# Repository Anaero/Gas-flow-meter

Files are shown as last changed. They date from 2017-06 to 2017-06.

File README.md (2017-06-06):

# Gas-flow-meter

The materials in this Repository have been designed to support data logging from the Anaero gas flow meter using a low cost Arduino based system (see http://www.anaero.co.uk/ for more information). All materials available from this repository are available subject to the terms and conditions of the Creative Commons CC BY-SA license (https://creativecommons.org/licenses/by-sa/4.0/).  Please see the licensing document in the repository for more information or visit the Creative Commons Web site.

No warranty, implied or otherwise, is granted in respect of the hardware designs or software available from this repository.

System overview - the hardware

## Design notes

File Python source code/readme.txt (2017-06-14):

Python source code developed using spyder 3.0.1 running with Python 3.5
Pyserial used to support serial comms with Arduino - available via Anaconda opensource platform (see https://www.continuum.io)

Startrun - used to transfer experimental data contained in setup.csv to Arduino at start of run.
Filegrab - transfers eventlog, hourly summary, daily summary and 4-hourly snapshot
Fastgrab - same as filegrab but only transfers eventlog and daily summary
Monitor - simple monitor program to 'eavesdrop' on what's happening

fastgrab/filegrab V2 - finds path for directory containing .exe file, checks for /data sub-directory and
creates sub-directory if not found. All data files are then written to /data sub-directory

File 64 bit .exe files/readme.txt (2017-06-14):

Windows 10 .exe files created from Python source code using Pyinstaller (see http://www.pyinstaller.org/).  

Note that Pyinstaller is not currently (as of June 2017) compatible with versions of Python above Python 3.5

fastgrab/filegrab V2 - finds path for folder containing executeable and creates /data sub-directory if it doesn't already exist
All log files are then written to the /data sub-directory

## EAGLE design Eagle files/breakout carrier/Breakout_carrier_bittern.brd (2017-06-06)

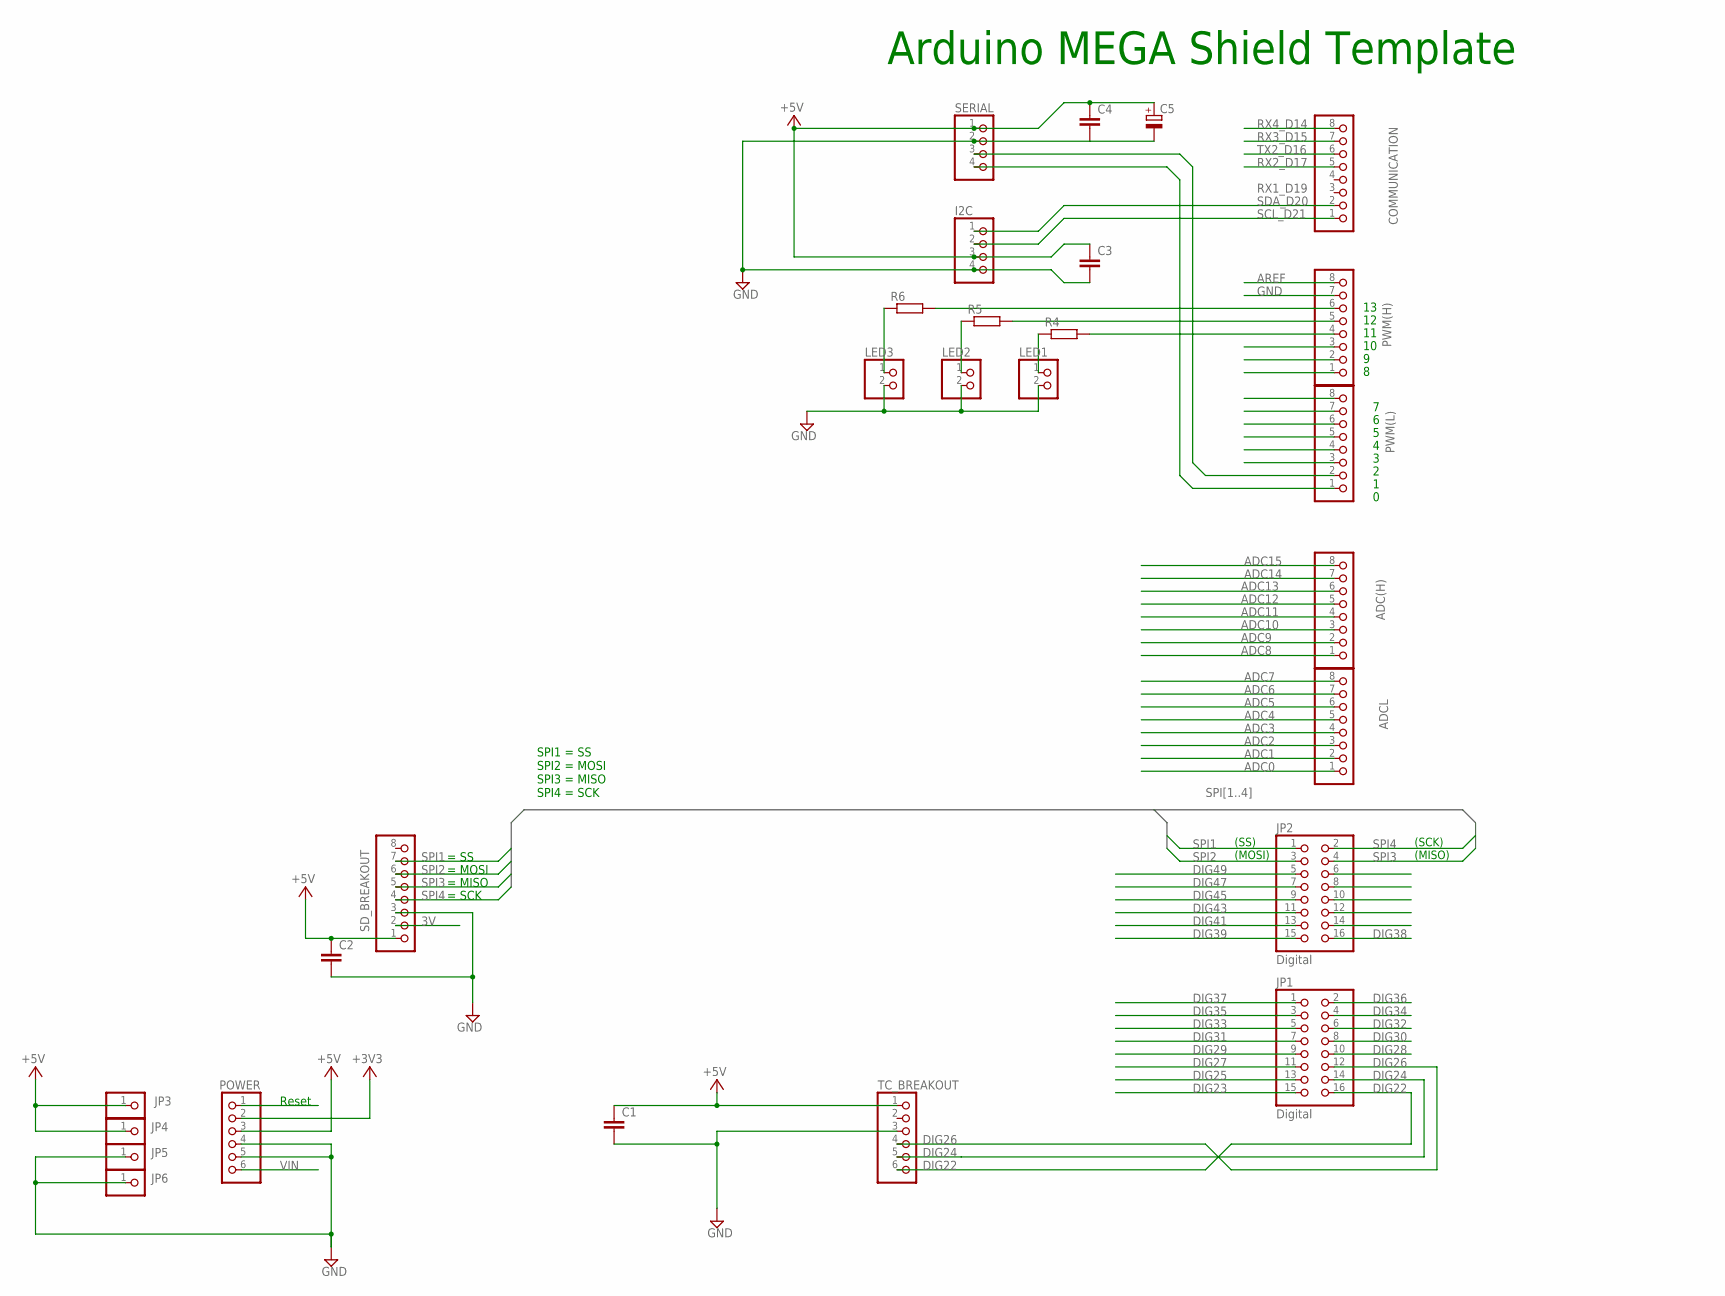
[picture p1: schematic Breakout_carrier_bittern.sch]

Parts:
ADC(H): PINHD-1X8; 1X08
ADCL: PINHD-1X8; 1X08
C1, C2, C3, C4: C-EU050-045X075; C050-045X075
C5: CPOL-EUE2.5-6; E2,5-6
COMMUNICATION: PINHD-1X8; 1X08
I2C: PINHD-1X4; 1X04
JP1, JP2: Digital; 2X08
JP3, JP4, JP5, JP6: PINHD-1X1; 1X01
LED1, LED2, LED3: PINHD-1X2; 1X02
POWER: PINHD-1X6; 1X06
PWM(H): PINHD-1X8; 1X08
PWM(L): PINHD-1X8; 1X08
R4, R5, R6: R-EU_0309/12; 0309/12
SD_BREAKOUT: PINHD-1X8; 1X08
SERIAL: PINHD-1X4; 1X04
TC_BREAKOUT: PINHD-1X6; 1X06

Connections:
3V: SD_BREAKOUT.2
+3V3: POWER.2
+5V: C1.1, C2.1, C3.1, C4.1, C5.+, I2C.3, JP3.1, JP4.1, POWER.3, SD_BREAKOUT.1, SERIAL.1, TC_BREAKOUT.1
ADC0: ADCL.1
ADC1: ADCL.2
ADC2: ADCL.3
ADC3: ADCL.4
ADC4: ADCL.5
ADC5: ADCL.6
ADC6: ADCL.7
ADC7: ADCL.8
ADC8: ADC(H).1
ADC9: ADC(H).2
ADC10: ADC(H).3
ADC11: ADC(H).4
ADC12: ADC(H).5
ADC13: ADC(H).6
ADC14: ADC(H).7
ADC15: ADC(H).8
AREF: PWM(H).8
DIG22: JP1.16, TC_BREAKOUT.6
DIG23: JP1.15
DIG24: JP1.14, TC_BREAKOUT.5
DIG25: JP1.13
DIG26: JP1.12, TC_BREAKOUT.4
DIG27: JP1.11
DIG28: JP1.10
DIG29: JP1.9
DIG30: JP1.8
DIG31: JP1.7
DIG32: JP1.6
DIG33: JP1.5
DIG34: JP1.4
DIG35: JP1.3
DIG36: JP1.2
DIG37: JP1.1
DIG38: JP2.16
DIG39: JP2.15
DIG41: JP2.13
DIG43: JP2.11
DIG45: JP2.9
DIG47: JP2.7
DIG49: JP2.5
GND: C1.2, C2.2, C3.2, C4.2, C5.-, I2C.4, JP5.1, JP6.1, LED1.2, LED2.2, LED3.2, POWER.4, POWER.5, PWM(H).7, SD_BREAKOUT.3, SERIAL.2, TC_BREAKOUT.3
unnamed: PWM(L).2, SERIAL.3
unnamed: PWM(H).4, R4.2
unnamed: PWM(H).5, R5.2
unnamed: PWM(H).6, R6.2
unnamed: LED3.1, R6.1
unnamed: LED2.1, R5.1
unnamed: LED1.1, R4.1
RESET: POWER.1
RX1_D19: PWM(L).1, SERIAL.4
RX2_D17: COMMUNICATION.5
RX3_D15: COMMUNICATION.7
RX4_D14: COMMUNICATION.8
SCL_D21: COMMUNICATION.1, I2C.2
SDA_D20: COMMUNICATION.2, I2C.1
SPI1: JP2.1, SD_BREAKOUT.7
SPI2: JP2.3, SD_BREAKOUT.6
SPI3: JP2.4, SD_BREAKOUT.5
SPI4: JP2.2, SD_BREAKOUT.4
TX2_D16: COMMUNICATION.6
VIN: POWER.6

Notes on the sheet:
Arduino MEGA Shield Template
(SS)
(MOSI)
(SCK)
(MISO)
Reset
= SCK
= MISO
= MOSI
= SS
SPI1 = SS SPI2 = MOSI SPI3 = MISO SPI4 = SCK

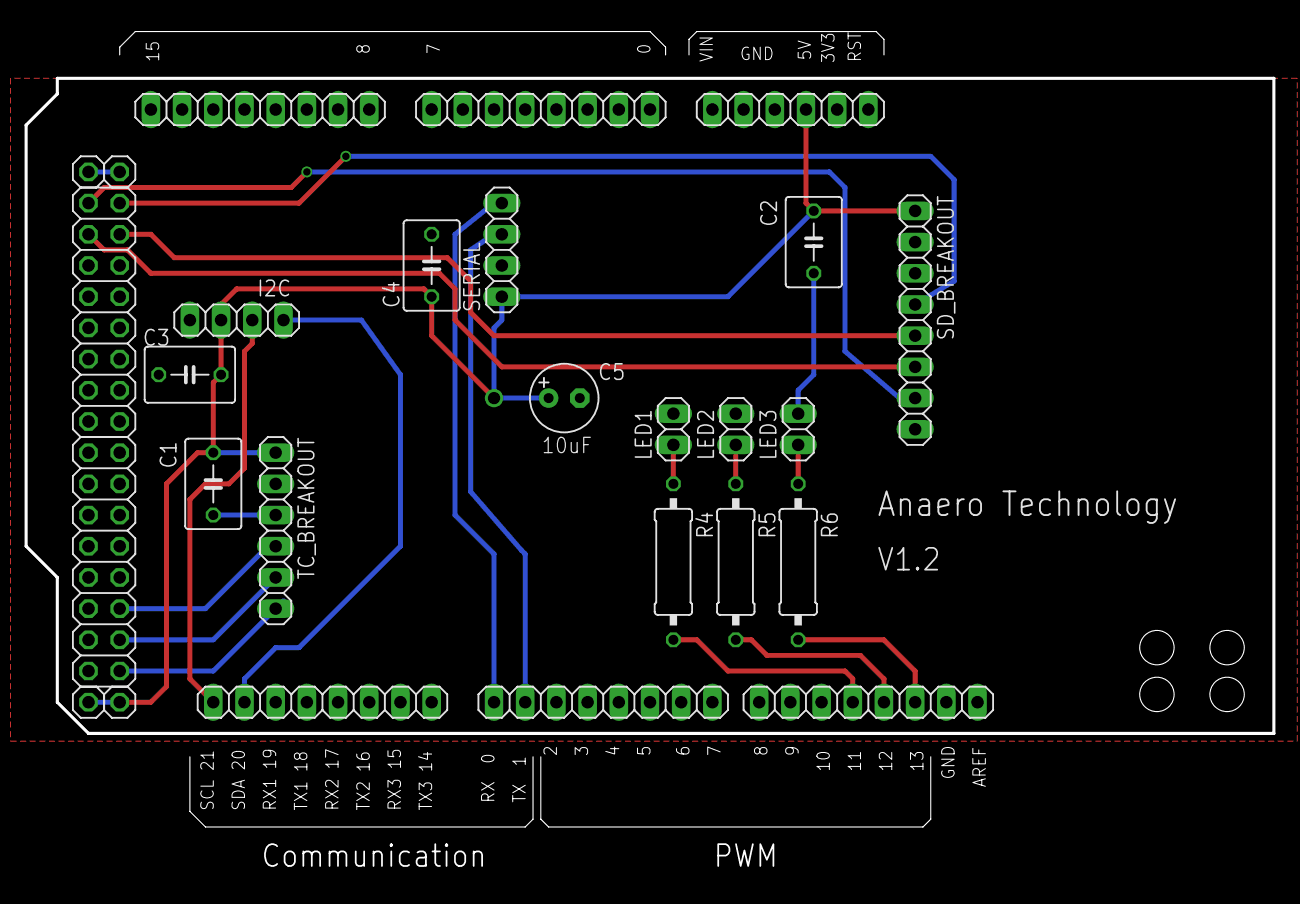
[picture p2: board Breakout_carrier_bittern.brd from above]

Board: 4 copper layers, 101.6 x 53.3 mm, 27 parts (0 on the bottom side), 19 nets.

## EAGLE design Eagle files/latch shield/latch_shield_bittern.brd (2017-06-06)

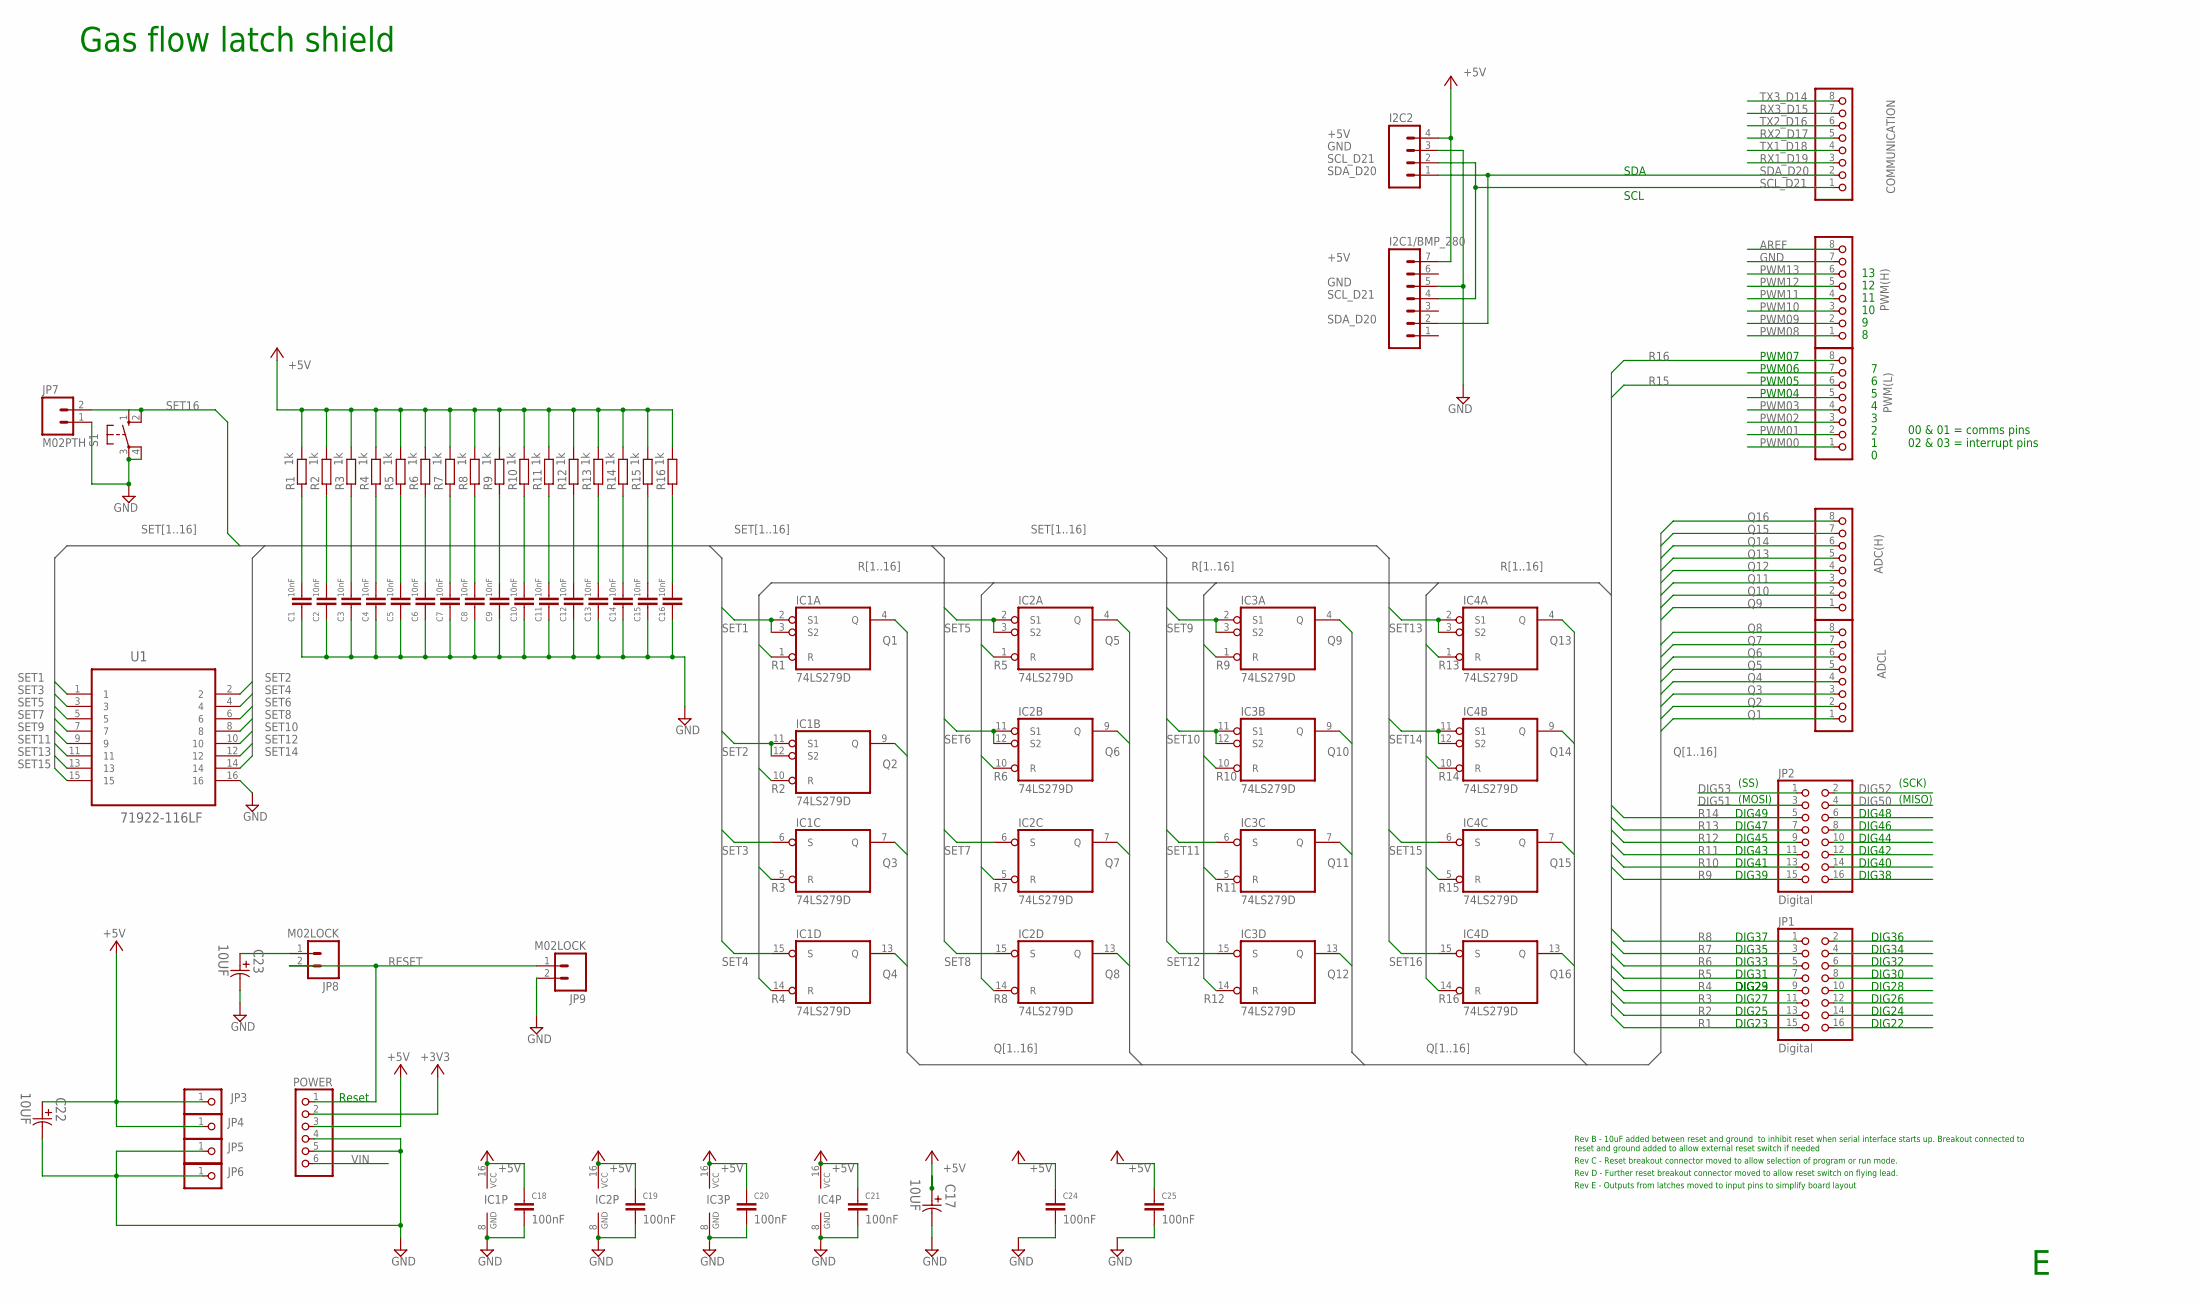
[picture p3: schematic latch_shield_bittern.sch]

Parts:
ADC(H): PINHD-1X8; 1X08
ADCL: PINHD-1X8; 1X08
C1, C2, C3, C4, C5, C6, C7, C8, C9, C10, C11, C12, C13, C14, C15, C16: 10nF; C0603
C17, C22, C23: 10UF; CAPAE530X610N
C18, C19, C20, C21, C24, C25: 100nF; C0603
COMMUNICATION: PINHD-1X8; 1X08
I2C1/BMP_280: M07; 1X07
I2C2: M04PTH; 1X04
IC1, IC2, IC3, IC4: 74LS279D; SO16
JP1, JP2: Digital; 2X08
JP3, JP4, JP5, JP6: PINHD-1X1; 1X01
JP7: M02PTH; 1X02
JP8, JP9: M02LOCK; 1X02_LOCK
POWER: PINHD-1X6; 1X06
PWM(H): PINHD-1X8; 1X08
PWM(L): PINHD-1X8; 1X08
R1, R2, R3, R4, R5, R6, R7, R8, R9, R10, R11, R12, R13, R14, R15, R16: 1k; R0603
S1: 10-XX; B3F-10XX
U1: 71922-116LF; FCI_71922-116LF

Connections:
+3V3: POWER.2
+5V: C17.1, C18.1, C19.1, C20.1, C21.1, C22.1, C24.1, C25.1, I2C1/BMP_280.7, I2C2.4, IC1.16 (VCC), IC2.16 (VCC), IC3.16 (VCC), IC4.16 (VCC), JP3.1, JP4.1, POWER.3, R1.2, R2.2, R3.2, R4.2, R5.2, R6.2, R7.2, R8.2, R9.2, R10.2, R11.2, R12.2, R13.2, R14.2, R15.2, R16.2
AREF: PWM(H).8
DIG50: JP2.4
DIG51: JP2.3
DIG52: JP2.2
DIG53: JP2.1
GND: C1.1, C2.1, C3.1, C4.1, C5.1, C6.1, C7.1, C8.1, C9.1, C10.1, C11.1, C12.1, C13.1, C14.1, C15.1, C16.1, C17.2, C18.2, C19.2, C20.2, C21.2, C22.2, C23.2, C24.2, C25.2, I2C1/BMP_280.5, I2C2.3, IC1.8 (GND), IC2.8 (GND), IC3.8 (GND), IC4.8 (GND), JP5.1, JP6.1, JP7.1, JP9.2, POWER.4, POWER.5, PWM(H).7, S1.3, S1.4 (P1), U1.16
unnamed: C23.1, JP8.1
PWM00: PWM(L).1
PWM01: PWM(L).2
PWM02: PWM(L).3
PWM03: PWM(L).4
PWM08: PWM(H).1
PWM09: PWM(H).2
PWM10: PWM(H).3
PWM11: PWM(H).4
PWM12: PWM(H).5
PWM13: PWM(H).6
Q1: ADCL.1, IC1.4 (Q)
Q2: ADCL.2, IC1.9 (Q)
Q3: ADCL.3, IC1.7 (Q)
Q4: ADCL.4, IC1.13 (Q)
Q5: ADCL.5, IC2.4 (Q)
Q6: ADCL.6, IC2.9 (Q)
Q7: ADCL.7, IC2.7 (Q)
Q8: ADCL.8, IC2.13 (Q)
Q9: ADC(H).1, IC3.4 (Q)
Q10: ADC(H).2, IC3.9 (Q)
Q11: ADC(H).3, IC3.7 (Q)
Q12: ADC(H).4, IC3.13 (Q)
Q13: ADC(H).5, IC4.4 (Q)
Q14: ADC(H).6, IC4.9 (Q)
Q15: ADC(H).7, IC4.7 (Q)
Q16: ADC(H).8, IC4.13 (Q)
R1: IC1.1 (R), JP1.15
R2: IC1.10 (R), JP1.13
R3: IC1.5 (R), JP1.11
R4: IC1.14 (R), JP1.9
R5: IC2.1 (R), JP1.7
R6: IC2.10 (R), JP1.5
R7: IC2.5 (R), JP1.3
R8: IC2.14 (R), JP1.1
R9: IC3.1 (R), JP2.15
R10: IC3.10 (R), JP2.13
R11: IC3.5 (R), JP2.11
R12: IC3.14 (R), JP2.9
R13: IC4.1 (R), JP2.7
R14: IC4.10 (R), JP2.5
R15: IC4.5 (R), PWM(L).6
R16: IC4.14 (R), PWM(L).8
RESET: JP8.2, JP9.1, POWER.1
RX1_D19: COMMUNICATION.3
RX2_D17: COMMUNICATION.5
RX3_D15: COMMUNICATION.7
SCL_D21: COMMUNICATION.1, I2C1/BMP_280.4, I2C2.2
SDA_D20: COMMUNICATION.2, I2C1/BMP_280.2, I2C2.1
SET1: C1.2, IC1.2 (S1), IC1.3 (S2), R1.1, U1.1
SET2: C2.2, IC1.11 (S1), IC1.12 (S2), R2.1, U1.2
SET3: C3.2, IC1.6 (S), R3.1, U1.3
SET4: C4.2, IC1.15 (S), R4.1, U1.4
SET5: C5.2, IC2.2 (S1), IC2.3 (S2), R5.1, U1.5
SET6: C6.2, IC2.11 (S1), IC2.12 (S2), R6.1, U1.6
SET7: C7.2, IC2.6 (S), R7.1, U1.7
SET8: C8.2, IC2.15 (S), R8.1, U1.8
SET9: C9.2, IC3.2 (S1), IC3.3 (S2), R9.1, U1.9
SET10: C10.2, IC3.11 (S1), IC3.12 (S2), R10.1, U1.10
SET11: C11.2, IC3.6 (S), R11.1, U1.11
SET12: C12.2, IC3.15 (S), R12.1, U1.12
SET13: C13.2, IC4.2 (S1), IC4.3 (S2), R13.1, U1.13
SET14: C14.2, IC4.11 (S1), IC4.12 (S2), R14.1, U1.14
SET15: C15.2, IC4.6 (S), R15.1, U1.15
SET16: C16.2, IC4.15 (S), JP7.2, R16.1, S1.1 (S), S1.2 (S1)
TX1_D18: COMMUNICATION.4
TX2_D16: COMMUNICATION.6
TX3_D14: COMMUNICATION.8
VIN: POWER.6

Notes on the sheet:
(SS)
(MOSI)
(SCK)
(MISO)
Reset
DIG22
DIG24
DIG26
DIG28
DIG30
DIG32
DIG34
DIG36
DIG38
DIG40
DIG42
DIG44
DIG46
DIG48
DIG23
DIG25
DIG27
DIG29
DIG31
DIG33
DIG35
DIG37
DIG39
DIG43
DIG41
DIG45
DIG47
DIG49
PWM07
PWM05
PWM04
PWM06
00 & 01 = comms pins 02 & 03 = interrupt pins
SDA
SCL

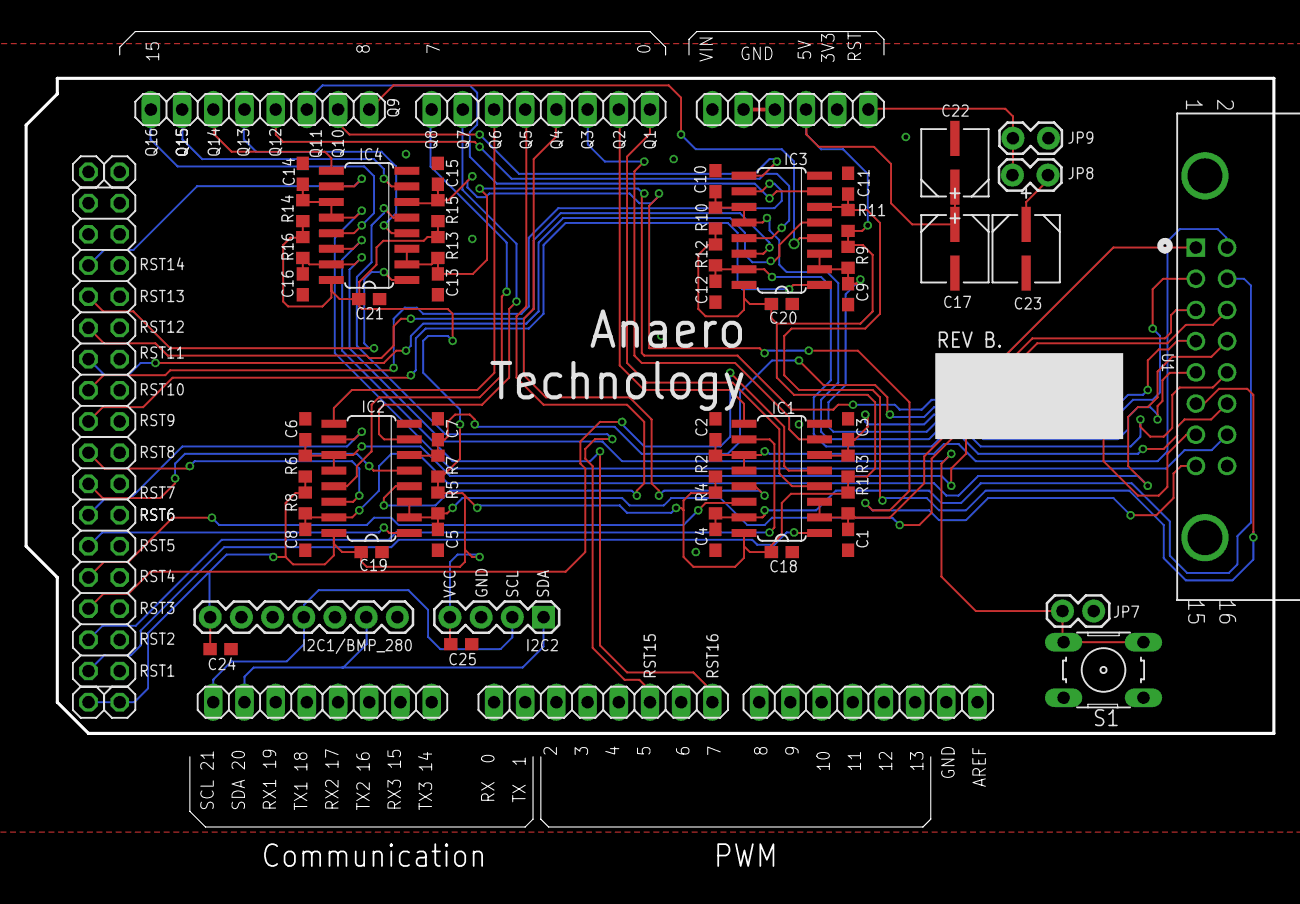
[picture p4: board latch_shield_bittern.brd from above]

Board: 4 copper layers, 101.6 x 53.3 mm, 64 parts (0 on the bottom side), 54 nets.

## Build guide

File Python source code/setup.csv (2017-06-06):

Sample description | In service | Inoculum only | Inoculum mass VS (g) | Sample mass VS (g) | Tumbler volume (ml)
Inoculum 1 | 1 | 1 | 15.46 | 0 | 5
Inoculum 2 | 1 | 1 | 15.48 | 0 | 5.2
Inoculum 3 | 1 | 1 | 15.5 | 0 | 5.17
Cellu 10 | 1 | 0 | 14.27 | 2.39 | 5.17
Cellu 11 | 1 | 0 | 14.28 | 2.42 | 5
Cellu 12 | 1 | 0 | 14.27 | 2.38 | 5
1623 Mar | 1 | 0 | 15.31 | 3.92 | 5.17
1623 Mar | 1 | 0 | 15.32 | 3.87 | 5
1623 Mar | 1 | 0 | 15.3 | 3.83 | 5
1624 Agri | 1 | 0 | 11.85 | 2.97 | 5
1624 Agri | 1 | 0 | 11.8 | 2.98 | 5.17
1624 Agri | 1 | 0 | 11.8 | 2.98 | 5.17
54 Bryn 1 | 1 | 0 | 11.92 | 3.1 | 5.17
54 Bryn 2 | 1 | 0 | 11.9 | 2.95 | 5.17
54 Bryn 3 | 1 | 0 | 11.88 | 2.96 | 5.17
End of data
Notes:
...To designate a reactor as inoculum only enter a 1 in column C otherwise enter 0
...Only tumblers which are marked as in service (a 1 in column B) will be monitored
...If a channel is not being used enter a 0 in column B
...The sample descriptions given in column A can be made up of any character or number combination but MUST NOT contain a comma!
...All cells in rows 2 to 16 MUST be populated - do not leave any blank or empty!
...Cell A17 should contain the words 'End of data'

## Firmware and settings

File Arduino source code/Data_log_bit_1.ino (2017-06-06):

 //
// Gas flow data logging program
//
// Bittern build 
//
// This version is for use with the Mark 2 latch shield, the Adafruit MAX31855K thermocouple amp and type K thermocouple, the BMP280 pressure sensor, the 
// Adafruit micro-SD breakout board and the Adafruit 16x2 RGB LCD display.
// I2C devices: BMP280 pressure sensor addr - 0x77; RGB LCD display - addr 0x20
// micro SD breakout uses hardware SDI (i/o pins 50, 51, 52, 53) with digital output 53 as Card Select
// MAX31855K thermocouple amp uses software SDI running on digital i/o pins 22-CLK, 24-CS and 26-DO (no DI pin needed)
// 
//
// 
//
// Time delay before attempting to clear any latches which have been set ~ 9 seconds
// ml/g output reported for inoc only channels as well as sample channels
// hour log and day log report both incremental and cumulative ml/g
// column headings only written to SD log files at very start of run
// inService channels now identified as inService(= 1), taken out of service by user in setup.csv (= 0), identified as stuck by Arduino (= -1)
// running monitor utility triggers reset attempt for any channels marked with inService = -1 (i.e. any which have been automatically removed from service by arduino)
// LED's on pins 13 (red), 12 (yellow), 11 (green)
// If temperature reported is below zero or below (disconected temp sensor) - last positive temp is used in calculations and alarm is set until problem clears
// Serial port data rate set to 57600 bps
// Serial timeout set to 500 ms
//
// Avocet build (retired 4/5/2017)
// time delay eolDelay introduced at the end of each line transmitted for compatibility with Bluetooth/slower machines
// dummy string added at laptop end to each line of setup data to ensure correct parsing when sample name starts with one or more digits
//
// Bittern build released 4/5/2017
// Build name displayed on LCD panel and sent to console at start up to aid identification/config management
// inoculumOnly variable changed from boolean to int to allow range check as startup data is transferred - helps to detect framing errors/range errors in setup data and/or parsing
// range checking on data transferred from laptop implemented, warnings issued if InService is other than 0 or 1, inoculum only is other than 0 or 1, tumbler volume less than
// 4ml or greater than 14 ml, inoculum only channels have a non zero entry in the sample VS column - provides added protection against user error and framing error in data transfer
// '^' used as end of line delimiter to allow extraneous characters in setup file to be skipped to avoid framing errors
// auto-reset performed at every pingcount cycle on any channels marked as stuck by arduino (i.e. where inService[i] = -1) - only truly stuck channels will remain stuck
// support for fastGrab utility added - reads back eventlog and daily log only (filgrab still works and does full file transfer)
// hangover time can be adjusted from setup.csv file by replacing 'End of data' with an integer between 8 and 35 seconds - default setting is ~ 15 seconds
// 
//

#include <Wire.h>
#include <SPI.h>
#include <SD.h>
//#include "Adafruit_MCP9808.h"
#include <Adafruit_MAX31855.h>
#include <Adafruit_Sensor.h>
#include <Adafruit_BMP280.h>
#include <Adafruit_RGBLCDShield.h>
#include <utility/Adafruit_MCP23017.h>
#define MAXDO   26
#define MAXCS   24
#define MAXCLK  22
//
// set up variable types using the SD utility libraries
//
Sd2Card card;
SdVolume volume;
SdFile root;
//
// set up sensor objects
// 
Adafruit_MAX31855 thermocouple(MAXCLK, MAXCS, MAXDO); // set up thermocouple object
Adafruit_BMP280 bme;                                  // set up BMP280 pressuere sensor object (using I2C bus option)
Adafruit_RGBLCDShield lcd = Adafruit_RGBLCDShield();  // set up LCD shield object
//
// set up i/o channels and arrays
//
const int chipSelect = 53;
byte Q[17];                   // mapping between between latch outputs (active high)and Arduino inputs
byte R[17];                   // mapping between Arduino outputs and latch resets (active low)
float sampleVS[16];           // mass of volatile solids in each sample under test (user provided)
float inocVS[16];             // mass of volatile solids from inoculum in each sample (user provided)
String alphaName1, alphaName2, alphaName3, alphaName4, alphaName5, alphaName6, alphaName7, alphaName8;           //set up string objects
String alphaName9, alphaName10, alphaName11, alphaName12, alphaName13, alphaName14, alphaName15, alphaName;      //for alphanumeric ch names
String discard;                // used to force parsing of setup data at end of line
long ChannelCount[17];        // used to store cumulative total of number of tumbles recorded per channel
float tumblerVol[16];         // calibrated volume of each tumbler
float totalVol[16];           // used to store cumulative total volume of gas collected on each channel at STP
float volThisTip[16];         // volume of gas at STP from the most recent tip 
float volThisDay[16];         // running total of volume of gas at STP during current day 
float volThisHour[16];        // running total of volume of gas at STP during current hour
int inService[17];            // marks channels as in service or out of service (0 = not in service, 1 = in service, -1 = removed from service following reset fail)
boolean resetFlag[17];        // used to indicate which channels (if any) need to be queued for reset after each latch scan
boolean delayFlag = false;    // binary flag to indicate at least one channel in need of reset
int inoculumOnly[16];         // marks those channels which contain only innoculum - use int rathern than bool to help detect errors in setup data transfer/parsing 
boolean gotTemp = false;      // flag to bypass temp get if just got
boolean gotPress = false;     // flag to bypass press get if just got
float netVol_per_gram[16];    // total volume less average of inoc only volume divided my mass of vol solids (so ml/g)
float netVol_per_gramDay[16]; // netVol_per_gram calculatede for this day
float netVol_per_gramHour[16];// netVol_per_gram calculated for this hour
int tipsThisDay[16];          // running total of tumbler tips during current day
int tipsThisHour[16];         // running total of tumbler tips during current hour
unsigned long time_offset;    // records time at which run commences
unsigned long timex;          // time in ms since start of run
double dtemp;
float temperature;            // temp reading
float baroPress;              // barometer presssure reading
float pressLast;              // stores last recorded valid pressure in case of sensor failure
float tempLast ;              // stores last recorded valid temp in case of sensor failure
float contAve;                // inoculum only output in ml per gram for each inoc only cell averaged over all inoc only channels
int n;                        // counter used to calculate final contAve average
int goFlag = 0;               // used for handshake between Arduino and Phython front end
int startMode = 1000;         // 1000 = normal cold start; 500 = recovery after unwanted reset (not programmed yet)
int alphaIndex;               // used to pass index to get_alphaName function
byte R_LED = 13; byte Y_LED = 12; byte G_LED = 11;  //assignement of Arduino pins to diagnostic LEDs
int ByteReceived = 0;
const int chipSelect1 = 53;
const char comma=(',');
int cardFound;
int cardPresent;
int snapTest;
long days=0;
int newDay=0;
int oldDay=0;
long hours=0;
int newHour=0;
int oldHour=0;
long mins=0;
int newMins=0;
int oldMins=0;
long secs=0;
int oldSecs=0;
int newSecs=0;
int secTest=0;
int incomingByte=0;
int  pingCount = 0;
int dispCount;
int hangTime = 15;                               // length of pause before attempting to clear latches that have been set
int hangTimeReset; 
int fastGrab = 0;                                // used to select full file transfer (filegrab utiltity) or eventlog and daily only (fastgrab utility)
File fSetup;
File fEventLog;
File fDaily;
File fHourly;
File fSnap;
byte sdByte;
int eolDelay=65;                                 // end of line delay to allow bluetooth/laptop to process
String fnameToCheck;
String fnameSetup = "setup.csv";
String fnameEvent = "eventlog.csv";
String fnameDaily = "daily.csv";
String fnameHourly = "hourly.csv";
String fnameSnap = "snapshot.csv";
String fnameError = "errorlog.csv";
//
//
//
void setup() {
//
// setup i/0 channel assignments
//  
   Q[1]=54, Q[2]=55, Q[3]=56, Q[4]=57, Q[5]=58, Q[6]=59, Q[7]=60, Q[8]=61;          // feed to arduino from latches 
   Q[9]=62, Q[10]=63, Q[11]=64, Q[12]=65, Q[13]=66, Q[14]=67, Q[15]=68, Q[16]=69;   // corresponds to A0 through A15
//
//
//
   R[1]=23, R[2]=25, R[3]=27, R[4]=29, R[5]=31, R[6]=33, R[7]=35, R[8]=37;          // latch reset lines
   R[9]=39, R[10]=41, R[11]=43, R[12]=45, R[13]=47, R[14]=49, R[15]=5, R[16]=7; 

//
// Set up pins as inputs and outputs
//
for (int i=1; i<=15; i++){
   pinMode(R[i], OUTPUT);
   pinMode(Q[i], INPUT);
   digitalWrite(R[i], HIGH);   digitalWrite(R[i], LOW);   digitalWrite(R[i], HIGH);
   }
//
//
//
   Serial.begin(57600);
   Serial.setTimeout(500);             // set serial timeout to 0.5 second - increase this if using manual input instead of Python utilities
   lcd.begin(16, 2); 
//
   pinMode(R_LED, OUTPUT);                                                         // set up pins to LEDs as outputs - nut used at the moment
   pinMode(Y_LED, OUTPUT);  
   pinMode(G_LED, OUTPUT); 

   digitalWrite(R_LED, HIGH);                                                       // turn on all LEDs
   digitalWrite(Y_LED, HIGH);
   digitalWrite(G_LED, HIGH);
// 
// program held here until something received on serial port
//
//
// Send reset message every 100ms until incoming data received
//   
   while(goFlag == 0) {
       Serial.println(F("Arduino has been reset"));
       delay(100);
       goFlag = Serial.available();
       }
   lcd.print("hello :-)       ");
   lcd.setCursor(0,1);
   lcd.print("getting ready...");
   delay(2000);
//
//
//
   lcd.setCursor(0,0);                                                          // dispaly bild name
   lcd.print("running         ");
   lcd.setCursor(0,1);
   lcd.print("Bittern build   ");
   delay(5000);
//      
   startMode = Serial.parseInt();                                               // read start mode number supplied by python utility
//       
   Serial.println();
   Serial.println(F("Arduino running - starting self test"));
   Serial.println();
   Serial.println(F("Running Bittern software build"));                         // display software build name
   Serial.println();
// 
   lcd.setCursor(0,0);                                                          // set up the LCD's number of columns and rows: 
   lcd.print("starting self   ");
   lcd.setCursor(0,1);
   lcd.print("test            ");
//
/*    code for MCP9808 I2C temp sensor
      if (!tempsensor.begin()) {                                                   // open temp sensor and check is OK
      Serial.println(F("Temperature sensor not responding"));
      while (1);                                                                // program will loop here continuously if no response from temp sensor
      }
   else {
       Serial.println(F("Temperature sensor OK"));       
       tempsensor.shutdown_wake(0);                                             // wake up temp sensor - required before reading temp
       delay(10);
       temperature = tempsensor.readTempC();
       delay(250);                                                              // give sensor time to respond!
       Serial.print(F("Temp: ")); Serial.print(temperature); Serial.println("C");                                        
       tempsensor.shutdown_wake(1);                                            // shutdown temp sensor to reduce power consumption       
       }
//
   delay(250);  // give time for temp sensor shutdown messaging to complete
*/
//
// Check thermocouple
//
   Serial.print("Internal Temp = ");
   Serial.println(thermocouple.readInternal());
   dtemp = thermocouple.readCelsius();
   if (isnan(dtemp)) {
     Serial.println(F("Thermocouple not registering - please check"));
   } else {
     temperature = (float) dtemp;
     Serial.print("Thermocouple reading is "); 
     Serial.print(temperature);
     Serial.println( "C");
   }
//
//
//
   if (!bme.begin()) {                                                              // open pressure sensor and check is OK
       Serial.println(F("Barometer not responding"));
       digitalWrite(R_LED, HIGH); digitalWrite(Y_LED, LOW);   digitalWrite(G_LED, LOW);   // set red LED to indicate problem
       lcd.setCursor(0,0);                                                                // set up the LCD's number of columns and rows: 
       lcd.print("problem with    ");
       lcd.setCursor(0,1);
       lcd.print("barometer       ");
       while (1);                                                                   // program will loop here in event of barometer failure
       }
   else{     
      Serial.println(F("Barometer OK"));
      bme.begin();                                                                  // re initialise pressure sensor
      delay(15);
      baroPress = bme.readPressure();                                               // take first reading to force BMP internals and discard  
      delay(15);
      baroPress = bme.readPressure();                                               // valid pressure reading
      delay(15);      
      baroPress = baroPress / 100; 
      Serial.print(F("Air pressure is: ")); Serial.print(baroPress); Serial.println(" hPa");
      }
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
void loop() { 
   timex = (millis() - time_offset);                            // capture current time before scanning latches
   uptime();                                                    // takes 'timex' variable and convert elapsed run time to days and hours mins and secs  
   screenTime();                                                // call function to print time since reset to LCD screen
//
// send updated time over serial link every 10 seconds (could do with converting to a function to improve readability)
//
   secTest = (newSecs / 10) * 10;
   if ((newSecs != oldSecs) && (secTest == newSecs)) {
      if (days <=9) {
         Serial.print("0");
         }
      Serial.print(days);
      Serial.print(":");
      if (hours <=9) {
         Serial.print("0");
         }
      Serial.print(hours);
      Serial.print(":");
      if (mins <=9) {
        Serial.print("0");
        }
      Serial.print(mins);
      Serial.print(":");
      if (secs <=9) {
         Serial.print("0");
         }      
      Serial.println(secs);         
      }  
//
// Serial comms bit done
//     
   if (oldDay != newDay) {                                                                  // check whether daylog or hourlog need to be writted to SD card
      write_day_log();  
//
// zero out day counters
//
      for (byte i=1; i<=15; i++) {
         tipsThisDay[i] = 0;
         volThisDay[i] = 0;  
         }
      }
   if (oldHour != newHour) {      
      write_hour_log();  
//
// zero out hour counters
//            
      for (byte i=1; i<=15; i++) {
         tipsThisHour[i] = 0;
         volThisHour[i] = 0.0;  
         }
      snapTest = (newHour/4) * 4;
      if (snapTest == newHour) {
         write_snapshot();
        }   
      }
//
// Now scan all in service latches and update data log accordingly
//   
   for(byte i=1; i <= 15; i++) {                                                            // check each channel in turn to see if any have tripped
      if((inService[i]== 1) && (digitalRead(Q[i])== HIGH)) {                                // identifies in service channels which have been triggered
         lcd.setCursor(0, 1);
         lcd.print("event on ch "); lcd.print(i);
         digitalWrite(Y_LED, HIGH);
         ChannelCount[i] = ChannelCount[i] + 1;                                             // increment relevant channel activity counter
         tipsThisDay[i] = tipsThisDay[i] + 1;
         tipsThisHour[i] = tipsThisHour[i] + 1;
         resetFlag[i] = true;                                                               // mark channel for reset - this can only happen if channel is in service at this point
         delayFlag = true;                                                                  // set delay flag to force delay before reset as at least one ch has triggered - no problem if set several times
//
// Get barometer reading if not already updated
//
         if(gotPress == false) {
            baroPress = bme.readPressure();
            delay(10);
            baroPress = baroPress / 100.0;                                                  // convert frpm pA to HpA
            digitalWrite(R_LED, LOW);                                                       // clear red LED
            lcd.setCursor(0, 0);                                                            //
            lcd.print("data log running");                                                  // reset screen message
            if (baroPress >= 1200.0){                                                       // excessive pressure used to indicate sensor fail/not connected
               digitalWrite(R_LED, HIGH);                                                   // set red LED to indicate problem
               lcd.setCursor(0, 0);
               lcd.print("bmp sensor alert");
               baroPress = pressLast;                                                       // substitute previous pressure reading
               }
            gotPress = true;
            pressLast = baroPress;
            }  
//
// Get temperature 
//         
         if(gotTemp == false) { 
            dtemp = thermocouple.readCelsius();                                      // get temp from thermocouple board
            delay(250);                                                              // allow I2C bus time to clear 
            temperature = (float) dtemp;                                             // convert to float from double
            digitalWrite(R_LED, LOW);                                                // clear red LED
            lcd.setCursor(0, 0);                                                     //
            lcd.print("data log running");                                           // reset screen message
            if (temperature <= 0.0 || isnan(dtemp)){                                                 // -ve or zero tepertature used to indicate sensor fail/not connected
// (isnan(dtemp))
               digitalWrite(R_LED, HIGH);                                            // set red LED to indicate problem
               lcd.setCursor(0, 0);
               lcd.print("tmp sensor alert");
               temperature = tempLast;                                               // substitute last above zero temperture
               }
            gotTemp = true;
            tempLast = temperature;
            }
//
// convert event(s) to stp and update total vol collected
//
         volThisTip[i] = ((baroPress * tumblerVol[i] * 273.0)/(1013.25 * (temperature + 273.0)));  
         totalVol[i] = totalVol[i] +  volThisTip[i];                                  // add vol at stp to previous totalVol
         volThisDay[i] = volThisDay[i] + volThisTip[i];
         volThisHour[i] = volThisHour[i] + volThisTip[i];                     
         }
      }
//
//  Scan of all 15 latches complete
//      
      gotTemp = false;
      gotPress = false;                                                                          
//
// do calculations and update results here to make sure most recent inoculum only events are included
//
   if(delayFlag == true) {                                                        // condition satisfied if one or more channels have tripped
      contAve = 0.0;
      n = 0;
      for(byte i=1; i <= 15; i++) {                                               // scan for inoculum only channels and calculate ml per gram output for each inoc only channel
          if((inService[i]== 1) && (inoculumOnly[i] == 1)) {                   // and average across all inoc only channels
//
             netVol_per_gram[i] = totalVol[i]/ inocVS[i];                         // calculate and update net vol per gram for inoc only channels
//
             contAve = (totalVol[i]/inocVS[i]) + contAve;                         // sum across all channels so average for innoculum only can be found
             n = n + 1; 
             }
          }
      contAve = contAve / (float) n;                                               // average volume per unit mass from inoculum only (control) channels     
//      
//    Now calculate vol per unit mass for ALL in service non-inoc channels -  even if sample channel hasn't tripped, inoc only channel(s) may have
//    so contribution to gas from inoculum may have changed
//      
      for(byte i=1; i<=15; i++){
         if((inService[i]== 1) && (inoculumOnly[i] == 0)) {
            netVol_per_gram[i] = (totalVol[i] - (inocVS[i] * contAve))/ sampleVS[i];
            }
         }
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

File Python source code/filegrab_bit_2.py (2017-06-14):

# -*- coding: utf-8 -*-
"""
Bittern build

filegrab_bit_2 changes from filegrab_bit_1

finds current working pathname and creates /data/ subdirectory if it doesn't already exist
all data files then written to /data/ subdirectory 

"""

import serial
import serial.tools.list_ports
import time
import msvcrt
import datetime
from sys import exit
import os,sys
from pathlib import Path
ser = serial.Serial()
#
# Find pathname for current directory
#
dirname=os.path.dirname(os.path.realpath(sys.argv[0]))
#
# Extend path to include /data/ sub-directory
#
dirname = dirname + '/data/'
#
# Convert string version of extended pathname to list (Python strings are immutable)
#
newname = list(dirname)
for i, c in enumerate(dirname):
#    print(i, c, newname[i])
    len = i 
#
# Change backslash characters into forward slash
#
for i in range (0, (len+1)):
#    print(newname[i]) 
    if newname[i] == '\x5C':
        newname[i] = '/'
#
# Convert list back to string
#
newpath = ''.join(newname)
#
# Create /data/ sub-directory if needed
#
path = Path(newpath  + 'testfile.txt')
path.parent.mkdir(parents=True, exist_ok=True)
#
# Fix pathname for sub-directory
#
subdir = newpath
#
#print(ser)
print()
print(">>> **********************************************************************************")
print(">>> anaero technology - www.anaero.co.uk - file upload utility")
print(">>> this utility performs an upload of all log files from the Arduino SD card")
print(">>> data logging will still remain active")
print()
print(">>> checking for /data/ sub-directory", subdir)
print(">>> sub-directory will be created if it doesn't already exist")
print()
print(">>> serial ports being used on this machine are:",'\n')
ports = list(serial.tools.list_ports.comports())
for p in ports:
    print ("    ",p,'\n')
print(">>> enter the name of the COM port the Arduino Mega 2560 is connected to")
print(">>> e.g. COM1 or COM2 or COM3 or COM4 or similar, and then press enter",'\n')
var = input(">>> ")
time.sleep(1)
print(">>> configuring serial port")
ser.port = var
ser.baudrate = 57600
ser.timeout = 180
ser.setDTR(False)
time.sleep(0.5)
print(">>> port configured")
print(">>> opening serial port")
try:
    ser.open()
except serial.serialutil.SerialException:
    print(">>> Arduino not connected - please check COM port and try again")
    print(">>> press any key to exit program")
    done = False
    while not done:
        if msvcrt.kbhit():
#        print ("you pressed",msvcrt.getch(),"so now i will quit")
            line = msvcrt.getch()        
            print (">>> keyboard input detected - quitting monitor")
            done = True
            exit(0) # Successful exit  
time.sleep(1.0)
print(">>> serial connection established")
print()
print(">>> requesting connection to Arduino - this may take a short while",'\n')
line = ser.readline()
line = line.rstrip()
while (line != b'ping'):      # wait for ping to be received then send request
    line = ser.readline()
    line = line.rstrip()
#    print(line)
time.sleep(0.01)
ser.write(b'9999x') 
print(">>> waiting - writeback request sent",'\n')
while (line != b'Connection request acknowledged....'):
    line = ser.readline()
    line = line.rstrip()
print(">>> connection request acknowledged....",'\n') 
while (line != b'starting eventlog.csv writeback'):
    line = ser.readline()
    line = line.rstrip()
    if(line == b'starting eventlog.csv writeback'):
        print(">>> ",line.decode(),'\n')
#
#   start upload of log files
#
#subdir = '\x5C' + 'data' + '\x5C'
fileName = 'eventlog_'
fileExtn = '.csv'
timeStamp = datetime.datetime.strftime(datetime.datetime.now(), '%Y_%m_%d_%H_%M')
fullName = subdir + fileName + timeStamp + fileExtn
f1 = open(fullName, 'wb')   # open file for binary write (replace existing)
f1.write(b'file uploaded: ')
line = datetime.datetime.strftime(datetime.datetime.now(), '%Y-%m-%d %H:%M:%S')
f1.write(line.encode())
f1.write(b',\n')    
while (line != b'writeback completed - eventlog.csv closed'):
    line = ser.readline()
    f1.write(line)
    line = line.rstrip()
    time.sleep(0.0001)
    print('\t', line.decode())
f1.close()
#
print()
while (line != b'starting snapshot.csv writeback'):
    line = ser.readline()
    line = line.rstrip()
    print('\t',line.decode())
fileName = 'snapshot_'
fileExtn = '.csv'
timeStamp = datetime.datetime.strftime(datetime.datetime.now(), '%Y_%m_%d_%H_%M')
fullName = subdir + fileName + timeStamp + fileExtn   
f2 = open(fullName, 'wb')   # open file for binary write (replace existing)
f2.write(b'file uploaded: ')
line = datetime.datetime.strftime(datetime.datetime.now(), '%Y-%m-%d %H:%M:%S')
f2.write(line.encode())
f2.write(b',\n')    
while (line != b'writeback completed - snapshot.csv closed'):
    line = ser.readline()
    f2.write(line)
    line = line.rstrip()
    print('\t', line.decode())    
f2.close()
print()
#
while (line != b'starting daily.csv writeback'):
    line = ser.readline()
    line = line.rstrip()
    print('\t', line.decode())
fileName = 'daily_'
fileExtn = '.csv'
timeStamp = datetime.datetime.strftime(datetime.datetime.now(), '%Y_%m_%d_%H_%M')
fullName = subdir + fileName + timeStamp + fileExtn    
f3 = open(fullName, 'wb')   # open file for binary write (replace existing)
f3.write(b'file uploaded: ')
line = datetime.datetime.strftime(datetime.datetime.now(), '%Y-%m-%d %H:%M:%S')
f3.write(line.encode())
f3.write(b',\n')
while (line != b'writeback completed - daily.csv closed'):
    line = ser.readline()
    f3.write(line)
    line = line.rstrip()
    print('\t', line.decode())    
f3.close()
print()
#
while (line != b'starting hourly.csv writeback'):
    line = ser.readline()
    line = line.rstrip()
    print('\t', line.decode())
fileName = 'hourly_'
fileExtn = '.csv'
timeStamp = datetime.datetime.strftime(datetime.datetime.now(), '%Y_%m_%d_%H_%M')
fullName = subdir + fileName + timeStamp + fileExtn    
f4 = open(fullName, 'wb')   # open file for binary write (replace existing)
f4.write(b'file uploaded: ')
line = datetime.datetime.strftime(datetime.datetime.now(), '%Y-%m-%d %H:%M:%S')
f4.write(line.encode())
f4.write(b',\n')
while (line != b'writeback completed - hourly.csv closed'):
    line = ser.readline()
    f4.write(line)
    line = line.rstrip()
    print('\t', line.decode())    
f4.close()                     
ser.close()
print()
print(">>> upload of logfiles complete :-)")   
print(">>> filegrab utility will close in 10 seconds")
time.sleep(10)
print(">>> bye...")
time.sleep(2)
exit # Successful exit

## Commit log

2017-06-06 Add files via upload
    Arduino source code for Bittern build
2017-06-06 Arduino code for data logger
2017-06-06 board layout
    [latch_shield_bittern.brd]
2017-06-06 setup template
    [setup.csv]
2017-06-06 Eagle files for application specific pcbs
2017-06-12 application specific pcb design files

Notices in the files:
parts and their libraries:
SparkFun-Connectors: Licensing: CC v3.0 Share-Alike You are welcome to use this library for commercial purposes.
